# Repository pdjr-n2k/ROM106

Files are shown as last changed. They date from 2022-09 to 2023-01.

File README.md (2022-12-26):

# ROM106 - NMEA 2000 relay output module

**ROM106** is a specialisation of
[NOP100](https://github.com/preeve9534/NOP100)
and implements a six channel NMEA 2000 relay output module which
presents on the host NMEA bus as a switchbank device with Class
Code 30 (Electrical Distribution) and Function Code 140 (Load
Controller).

The module transmits PGN 127501 Binary Status Report messages and
responds to PGN 127502 Switch Bank Control messages addressed to
the module's instance number.

The module is powered from the host NMEA bus and has an LEN of 0.5.

## Relay outputs

**ROM106**'s relay output sub-system consists of six bistable relays
with zero-volt common (CO), normally-open (NO) and normally-closed (NC)
terminals availble for the connection of external circuits.

Relay connections are rated for a maximum of 5A at up to 220VAC
or 30VDC.

## Relay operation and status reporting

**ROM106** accepts PGN 127502 Switch Bank Control messages addressed
to its module's instance number, updating its relay outputs to the
requested states.
Operation of individual relays is queued so that any request for state
change of multiple relays cannot result in a possibly problematic
concurrent relay switching load.

The module reports module status by regularly broadcasting a PGN 127501
Binary Status Report message.
Additionally, a report is broadcast immediately following the receipt and
handling of a PGN 127502 Switch Bank Control message.
The regular transmission interval can be configured by the user.

## Module configuration

**ROM106** understands the following configuration parameters.

| Address | Name | Default value | Description |
| :---: | :--- | :---: | :--- |
| 0x01 | MODULE INSTANCE NUMBER | 0xFF | Used as a unique identifier for this switchbank. Must be set by the user to a value between 0 and 252 before the module will transmit status reports. |
| 0x02 | PGN 127501 TRANSMIT INTERVAL | 0x04 | Sets the basic transmit interval for broadcast of module status reports.|

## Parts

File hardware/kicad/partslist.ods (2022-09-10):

 |  |  | Quantity | Supplier | Order No | Qtty in pack | Order Qtty | Unit cost | Item Cost
> C1, C2 | 560pF | D5.0, P2.50 | 2 | Farnell | 1835017 | 1 | 2 | 0.09 | 0.17
> C3, C4 | 100nF | D5.0, P2.50 | 2 | Farnell | 1457568 | 1 | 2 | 1.17 | 2.34
> D1-D4, D8, D9 | 1N4007 | DO-35 SOD27 P2.54 | 6 | Farnell | 2889101 | 5 | 2 | 0.23 | 0.45
> D5-D7 | PWR/TX | LED D3.0, P2.54 | 3 | Farnell | 1735246 | 5 | 1 | 0.31 | 0.31
F1 | 100mA | Littelfuse 395, P5.08 | 1 | Farnell | 2786454 | 1 | 1 | 3.69 | 3.69
F2 | 1A | Littelfuse 395, P5.08 | 1 | Farnell | 2786457 | 1 | 1 | 0.82 | 0.82
J1 | NPN SENSOR | Phoenix MPT 1x03 P2.54 | 1 | Farnell | 3041360 | 1 | 1 | 1.94 | 1.94
J2 | Screw_Terminal_01x05 | Phoenix MPT 1x05 P2.54 | 1 | Farnell | 2776439 | 1 | 1 | 3.20 | 3.20
J3 | M12-5PIN | Phoenix MPT 1x04 P2.54 | 1 | Farnell | 3041414 | 1 | 1 | 1.05 | 1.05
J4 | RELAYS | Phoenix MPT 1x06 P2.54 | 1 | Farnell | 3041426 | 1 | 1 | 3.70 | 3.70
> K1, K2 | Form C Relay | RS_RELAY_476-757 | 2 | RS | 476-757 | 1 | 2 | 2.29 | 4.58
> Q1, Q2 | 2N2219 | TO-39-3 | 2 | Farnell | 1611599 | 1 | 2 | 2.65 | 5.30
> R1-R4 | 1K4, 1W | DIN0207 L6.3 D2.5 P2.54 | 4 | Farnell | 6534478 | 10 | 1 | 0.40 | 0.40
> R5,R6,R8,R13 | 4K7, 125mW | DIN0204 L3.6 D1.6 P2.54 | 4 | Farnell | 9343253 | 5 | 1 | 0.03 | 0.03
> R7,R9,R10 | 200R, 125mW | DIN0204 L3.6 D1.6 P5.08 | 3 | Farnell | 9342770 | 5 | 1 | 0.03 | 0.03
> R11, R12 | 100R | DIN0204 L3.6 D1.6 P5.08 | 2 | Farnell | 9342397 | 5 | 1 | 0.03 | 0.03
SW1 | INSTANCE | DIP SPSTx08 Slide W7.62 P2.54 LowProfile | 1 | Farnell | 2452332 | 1 | 1 | 0.85 | 0.85
U1 | CNY74-4H | DIP-16 W7.62 | 1 | Farnell | 1045432 | 1 | 1 | 1.70 | 1.70
U2 | Teensy_3.2 | Teensy 32 LC | 1 | Pimoroni | TEENSY3.2 | 1 | 1 | 18.00 | 18.00
U3 | TEC2-2411WI | DCDC TRACO THT | 1 | Farnell | 2854919 | 1 | 1 | 8.07 | 8.07
U4 | MCP2551-I-P | DIP-8 W7.62 | 1 | Farnell | 1292240 | 1 | 1 | 0.90 | 0.90
E1 | Enclosure | RS 80x80 ABS | 1 | RS | 919-0357 | 1 | 1 | 2.63 | 2.63
 |  |  |  |  |  |  |  | TOTAL | 60.19

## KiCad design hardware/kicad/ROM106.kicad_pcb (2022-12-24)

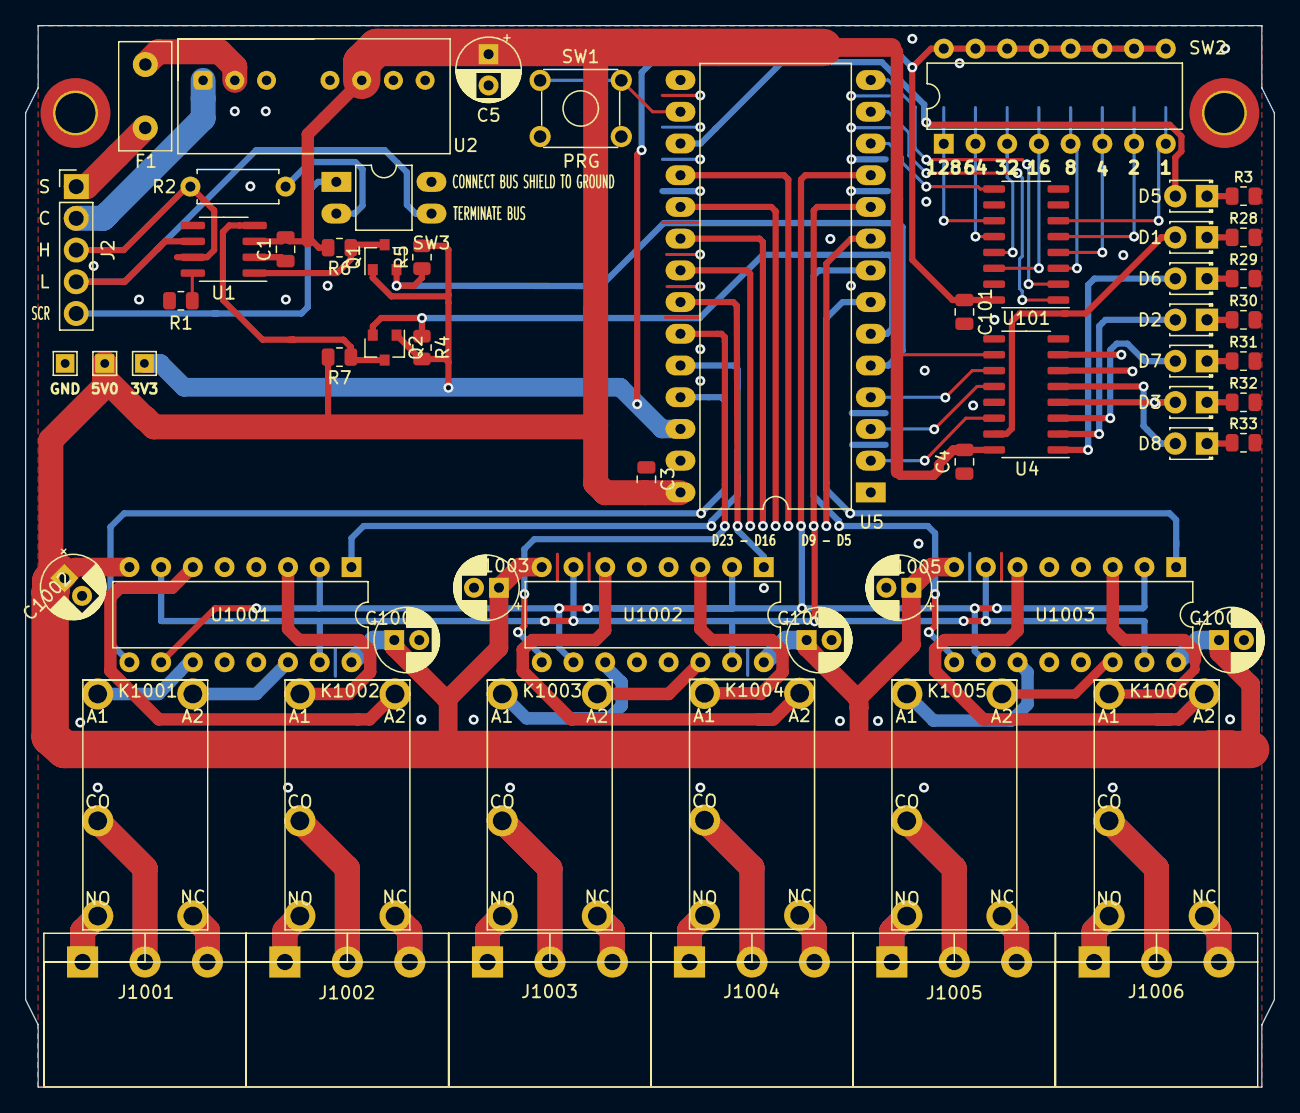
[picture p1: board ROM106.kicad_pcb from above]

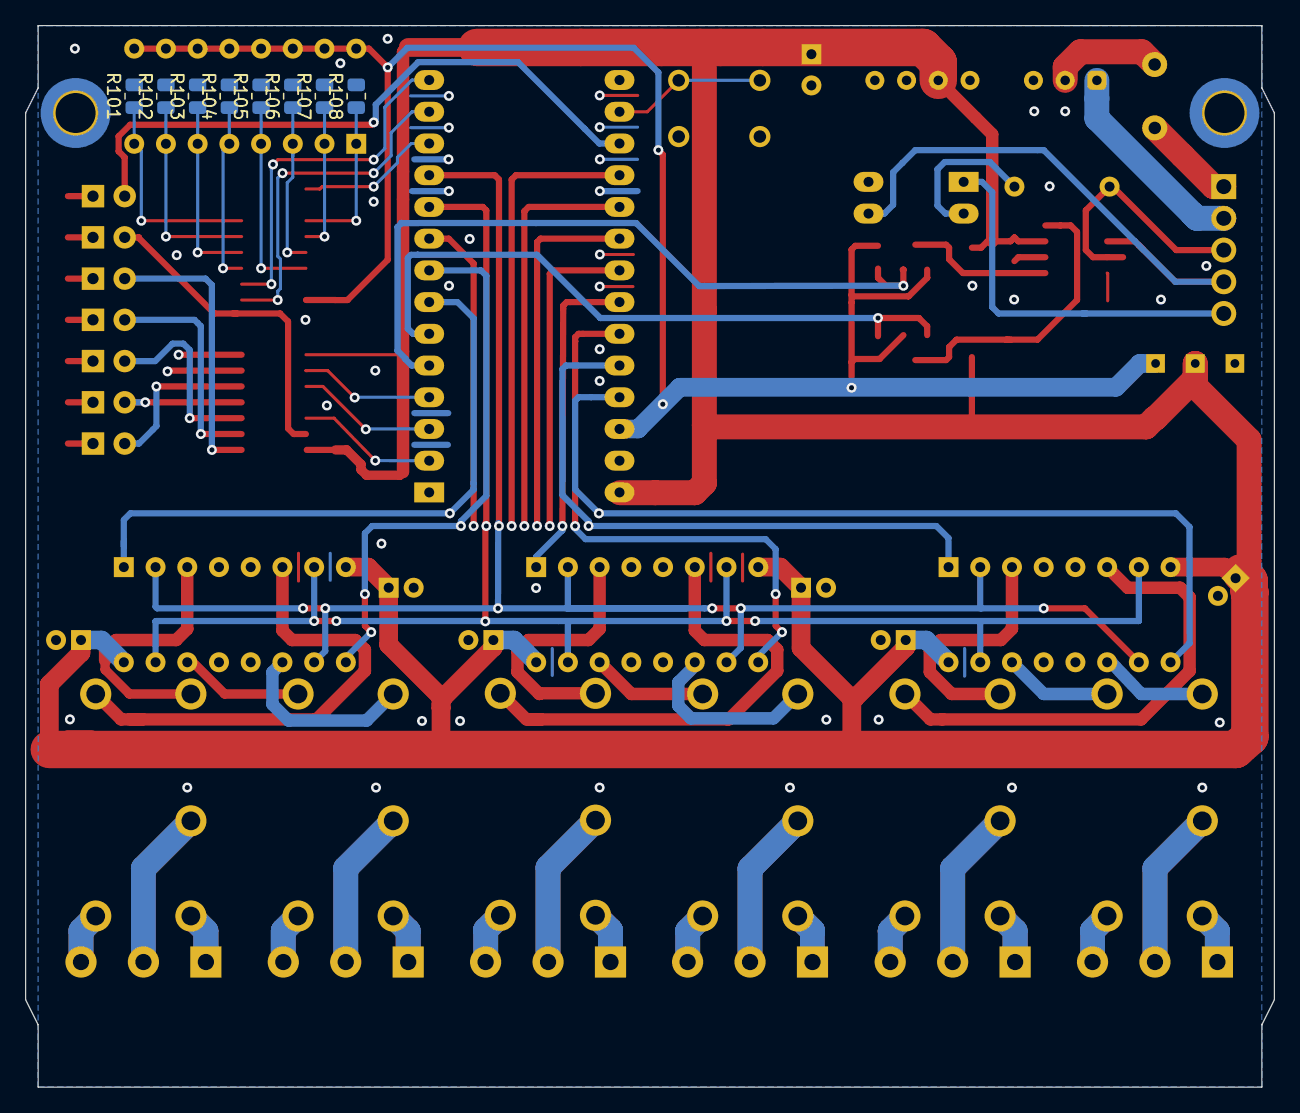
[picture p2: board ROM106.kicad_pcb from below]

Board: 2 copper layers, 100.0 x 85.0 mm, 68 parts (8 on the bottom side), 82 nets.

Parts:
C1, C3, C4, C101: 100nF; C_0805_2012Metric
C5: 100nF; CP_Radial_D5.0mm_P2.50mm
C1001, C1002, C1003, C1004, C1005, C1006: 100nF; CP_Radial_D5.0mm_P2.00mm
D1, D2, D3, D5, D6, D7, D8: LED; LED_D1.8mm_W3.3mm_H2.4mm
F1: 1A; Fuse_Littelfuse_395Series
J2: CAN; PinHeader_1x05_P2.54mm_Vertical
J1001, J1002, J1003, J1004, J1005, J1006: Screw_Terminal_01x03; 8971187_3_PIN_5MM_PLUGGABLE_HEADER
K1001, K1002, K1003, K1004, K1005, K1006: PE014F05
Q1, Q2: BSS138; SOT-23
R1, R101, R102, R103, R104, R105, R106, R107, R108: 4K7 0.125W; R_0805_2012Metric
R2: 120R 0.5W; R_Axial_DIN0207_L6.3mm_D2.5mm_P7.62mm_Horizontal
R3, R28, R29, R30, R31, R32, R33: 560R; R_0805_2012Metric
R4, R5, R6, R7: 10K 0.125W; R_0805_2012Metric
SW1: PRG; SW_TH_Tactile_Omron_B3F-10xx
SW2: INSTANCE; DIP-16_W7.62mm
SW3: BUS; DIP-4_W7.62mm_LongPads
TEST 5V0, TEST 5V0#2: TestPoint_THTPad_1.5x1.5mm_Drill0.7mm
U1: MCP2551-I-P; SOIC-8_3.9x4.9mm_P1.27mm
U2: TMR-2-2411; TMR_2411
U4: 74HCT595; SO-16_3.9x9.9mm_P1.27mm
U5: Teensy_4.0; DIP-28_W15.24mm_LongPads
U101: 74HC165; SO-16_3.9x9.9mm_P1.27mm
U1001, U1002, U1003: L293D; DIP-16_W7.62mm

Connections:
+3V3: C101.1, Q1.1, Q2.1, R4.2, R5.2, SW2.9, SW2.10, SW2.11, SW2.12, SW2.13, SW2.14, SW2.15, SW2.16, TEST 5V0.1, U5.26, U101.16
+5V: C1.1, C3.1, C4.1, C5.1, C1001.1, C1002.1, C1003.1, C1004.1, C1005.1, C1006.1, R6.2, R7.2, TEST 5V0#2.1, U1.3, U2.6, U4.10, U4.16, U5.28, U1001.8, U1001.16, U1002.8, U1002.16, U1003.8, U1003.16
/CAN_RX: Q2.2, R4.1, U5.6
/CAN_TX: Q1.2, R5.1, U5.5
/D5: U5.7, U1003.1
/D6: U5.8, U1003.9
/D8: U5.10, U1001.7, U1001.15, U1002.7, U1002.15, U1003.7, U1003.15
/D9: U5.11, U1001.2, U1001.10, U1002.2, U1002.10, U1003.2, U1003.10
/D20: U5.22, U1002.1
/D21: U5.23, U1002.9
/D22: U5.24, U1001.1
/D23: U5.25, U1001.9
/PISO_CP: U5.14, U101.2
/PISO_PL: U5.13, U101.1
/PISO_Q7: U5.12, U101.9
/PRG: SW1.1, SW1.2, U5.16
/SIPO_CLOCK: U4.11, U5.4
/SIPO_DATA: U4.14, U5.2
/SIPO_LATCH: U4.12, U5.3
GND: C1.2, C3.2, C4.2, C5.2, C101.2, C1001.2, C1002.2, C1003.2, C1004.2, C1005.2, C1006.2, R1.1, R3.2, R28.2, R29.2, R30.2, R31.2, R32.2, R33.2, R101.2, R102.2, R103.2, R104.2, R105.2, R106.2, R107.2, R108.2, SW1.3, SW1.4, SW3.4, U1.2, U2.7, U4.8, U4.13, U5.1, U5.27, U101.8, U101.10, U101.15, U1001.4, U1001.5, U1001.12, U1001.13, U1002.4, U1002.5, U1002.12, U1002.13, U1003.4, U1003.5, U1003.12, U1003.13
unnamed: D1.1, R28.1
unnamed: D1.2, U4.15
unnamed: D2.1, R30.1
unnamed: D2.2, U4.2
unnamed: D3.1, R32.1
unnamed: D3.2, U4.4
unnamed: D5.1, R3.1
unnamed: D5.2, U5.17
unnamed: D6.1, R29.1
unnamed: D6.2, U4.1
unnamed: D7.1, R31.1
unnamed: D7.2, U4.3
unnamed: D8.1, R33.1
unnamed: D8.2, U4.5
unnamed: F1.1, J2.1
unnamed: F1.2, U2.2
unnamed: J2.2, U2.1
unnamed: J2.3, R2.1, U1.7
unnamed: J2.4, SW3.3, U1.6
unnamed: J2.5, SW3.1
unnamed: J1001.1, K1001.14
unnamed: J1001.2, K1001.7
unnamed: J1001.3, K1001.1
unnamed: J1002.1, K1002.14
unnamed: J1002.2, K1002.7
unnamed: J1002.3, K1002.1
unnamed: J1003.1, K1003.14
unnamed: J1003.2, K1003.7
unnamed: J1003.3, K1003.1
unnamed: J1004.1, K1004.14
unnamed: J1004.2, K1004.7
unnamed: J1004.3, K1004.1
unnamed: J1005.1, K1005.14
unnamed: J1005.2, K1005.7
unnamed: J1005.3, K1005.1
unnamed: J1006.1, K1006.14
unnamed: J1006.2, K1006.7
unnamed: J1006.3, K1006.1
unnamed: K1001.2, U1001.14
unnamed: K1001.6, U1001.11
unnamed: K1002.2, U1001.6
unnamed: K1002.6, U1001.3
unnamed: K1003.2, U1002.14
unnamed: K1003.6, U1002.11
unnamed: K1004.2, U1002.6
unnamed: K1004.6, U1002.3
unnamed: K1005.2, U1003.14
unnamed: K1005.6, U1003.11
unnamed: K1006.2, U1003.6
unnamed: K1006.6, U1003.3
unnamed: Q1.3, R6.1, U1.1
unnamed: Q2.3, R7.1, U1.4
unnamed: R1.2, U1.8
unnamed: R2.2, SW3.2
unnamed: R101.1, SW2.8, U101.6
unnamed: R102.1, SW2.7, U101.5
unnamed: R103.1, SW2.6, U101.4
unnamed: R104.1, SW2.5, U101.3
unnamed: R105.1, SW2.4, U101.14
unnamed: R106.1, SW2.3, U101.13
unnamed: R107.1, SW2.2, U101.12
unnamed: R108.1, SW2.1, U101.11

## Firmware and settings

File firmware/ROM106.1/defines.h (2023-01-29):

/**
 * @file defines.h
 * @author Paul Reeve (preeve@pdjr.eu)
 * @brief CPP define directives for ROM106.
 * @copyright Copyright (c) 2023
 */

/**********************************************************************
 * @brief GPIO aliases. 
 */
#define GPIO_RELAY1_ENABLE GPIO_D23
#define GPIO_RELAY2_ENABLE GPIO_D22
#define GPIO_RELAY3_ENABLE GPIO_D21
#define GPIO_RELAY4_ENABLE GPIO_D20
#define GPIO_RELAY5_ENABLE GPIO_D6
#define GPIO_RELAY6_ENABLE GPIO_D5
#define GPIO_RELAY_SET GPIO_D8
#define GPIO_RELAY_RST GPIO_D9
#define GPIO_RELAY_CONTROL_OUTPUT_PINS { GPIO_RELAY1_ENABLE, GPIO_RELAY2_ENABLE, GPIO_RELAY3_ENABLE, GPIO_RELAY4_ENABLE, GPIO_RELAY5_ENABLE, GPIO_RELAY6_ENABLE, GPIO_RELAY_SET, GPIO_RELAY_RST }

/**********************************************************************
 * @brief Device and product information overrides for ROM106.
 */
#define DEVICE_CLASS 30                 // Electrical Distribution
#define DEVICE_FUNCTION 140             // Load Controller
#define DEVICE_UNIQUE_NUMBER 849        // Bump me?

#define PRODUCT_CODE 002
#define PRODUCT_FIRMWARE_VERSION "1.1.0 (Jun 2022)"
#define PRODUCT_LEN 1
#define PRODUCT_SERIAL_CODE "002-849"   // PRODUCT_CODE + DEVICE_UNIQUE_NUMBER
#define PRODUCT_TYPE "ROM106"           // The product name?
#define PRODUCT_VERSION "1.0 (Mar 2022)"

/**********************************************************************
 * @brief PGN overrides for ROM106.
 * */
void handlePGN127502(const tN2kMsg &n2kMsg);

#define NMEA_TRANSMITTED_PGNS { 127501L, 0 }
#define NMEA_RECEIVED_PGNS  { { 127502L, handlePGN127502 }, { 0L, 0 } }

/**********************************************************************
 * Module configuration stuff.
 */
#define MODULE_CONFIGURATION_SIZE 4

#define MODULE_CONFIGURATION_INSTANCE_INDEX 1
#define MODULE_CONFIGURATION_PGN127501_TRANSMIT_PERIOD_INDEX 2
#define MODULE_CONFIGURATION_PGN127501_TRANSMIT_OFFSET_INDEX 3

#define MODULE_CONFIGURATION_INSTANCE_DEFAULT 0xff
#define MODULE_CONFIGURATION_PGN127501_TRANSMIT_PERIOD_DEFAULT 0x02
#define MODULE_CONFIGURATION_PGN127501_TRANSMIT_OFFSET_DEFAULT 0x00

#define MODULE_CONFIGURATION_DEFAULT { \
  MODULE_CONFIGURATION_CAN_SOURCE_DEFAULT, \
  MODULE_CONFIGURATION_INSTANCE_DEFAULT, \
  MODULE_CONFIGURATION_PGN127501_TRANSMIT_PERIOD_DEFAULT, \
  MODULE_CONFIGURATION_PGN127501_TRANSMIT_OFFSET_DEFAULT \
}

/**********************************************************************
 * Number of milliseconds between checks on switch input channel state.
 */
#define RELAY_PROCESS_INTERVAL 100       // Process relay outputs every n ms

/**********************************************************************
 * Maximum number of entries in the relay operation queue.
 */
#define RELAY_OPERATION_QUEUE_SIZE 10       // Max number of entries

/**********************************************************************
 * Frequency of relay queue processing.
 */
#define RELAY_OPERATION_QUEUE_INTERVAL 20UL

#define ON_N2K_OPEN
#define CONFIGURATION_VALIDATOR

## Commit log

2022-09-17 Add PCB silk labels
    [ROM104.kicad_pcb]
2022-09-17 PCB silk update
    [ROM104.kicad_pcb]
2022-09-18 Switch PSU to 2W
    [ROM104.kicad_pcb, ROM104.sch]
2022-09-18 Revise silk screen
    [ROM104.kicad_pcb]
2022-09-18 Change relay terminal
    [ROM104.kicad_pcb, ROM104.sch]
2022-09-18 PCB tweak
    [ROM104.kicad_pcb]
2022-09-19 Change resistor footprints
    [ROM104.kicad_pcb, ROM104.sch]
2022-09-19 Restore 1/4W resistor footprints
    [ROM104.kicad_pcb, ROM104.sch]
2022-09-20 Update PCB
    [ROM104.kicad_pcb, ROM104.sch]
2022-09-25 PCB resize
    [ROM104.kicad_pcb, ROM104.sch]
2022-09-25 New PCB layout
    [ROM104.kicad_pcb, ROM104.sch]
2022-09-26 Add PRG switch
    [ROM104.kicad_pcb, ROM104.sch]
2022-09-27 PCB update
    [ROM104.kicad_pcb, ROM104.sch]
2022-09-27 Revised PCB
    [ROM104.kicad_pcb, ROM104.sch]
2022-09-27 README update.
    [ROM104.kicad_pcb]
2022-09-28 Add PRG debounce
    [ROM104.kicad_pcb, ROM104.sch]
2022-10-25 PCB reroute
    [ROM104.kicad_pcb, ROM104.sch]
2022-11-07 PCB reshape
    [ROM104.kicad_pcb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]
2022-12-19 Redraw PCB
    [ROM106-new.kicad_pcb, ROM106.kicad_pcb, ROM106.sch]
2022-12-20 Relay PCB
    [NMEA2000-COMMON.sch, ROM106.sch]
2022-12-24 PCB layout
    [ROM106.kicad_pcb]
